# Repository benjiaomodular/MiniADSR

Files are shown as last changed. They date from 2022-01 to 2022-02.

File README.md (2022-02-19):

# MiniADSR

A four-parameter envelope generator based on Rene Schmitz' [The Fastest Envelope in the West](https://www.schmitzbits.de/adsr.html). More info on my website: https://benjiaomodular.com/post/2022-02-02-mini-adsr/

# Versions

## 1.0.1
Quick fixes for v1.0
- Fixed connection of R7 to Q2 pin 1
- Updated C2 value to 10uF
- Change sustain pot from 1M to 10k
- C3 from 100uF to 1uF
- Added version numbers
- Flipped power connectors 180deg to accomodate larger IDC connectors.

## 1.0
Initial design.

### Issues
- Wrong connection from R7
- Wrong value for C3 and Sustain pot

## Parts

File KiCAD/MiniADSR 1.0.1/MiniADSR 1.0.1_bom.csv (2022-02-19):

Reference | Quantity | Value | Footprint | Datasheet | Part # | Part Page
C1 | 1 | 10nF | Capacitor_THT:C_Rect_L7.2mm_W2.5mm_P5.00mm_FKS2_FKP2_MKS2_MKP2 | ~ | MMK5103K50J01L4BULK
C2 | 1 | 10uF | Capacitor_THT:CP_Radial_D5.0mm_P2.50mm | ~ | UVR1E100MDD1TD
C3 | 1 | 1uF* | Capacitor_THT:CP_Radial_D5.0mm_P2.50mm | ~ | ESC105M050AC3AA
C4 C5 | 2 | 100uF | Capacitor_THT:CP_Radial_D5.0mm_P2.50mm | ~ | ESH107M010AC3AA
C6 C7 | 2 | 100nF | Capacitor_THT:C_Rect_L7.2mm_W2.5mm_P5.00mm_FKS2_FKP2_MKS2_MKP2 | ~ | R82DC3100AA50K
D1 D2 D3 D4 D5 | 5 | 1N4148 | Diode_THT:D_DO-35_SOD27_P7.62mm_Horizontal | https://assets.nexperia.com/documents/data-sheet/1N4148_1N4448.pdf | 1N4148
D6 | 1 | PWR_LED | LED_THT:LED_D3.0mm | ~
D7 | 1 | OUTPUT_LED | LED_THT:LED_D3.0mm | ~
J1 | 1 | INPUT | benjiaomodular:AudioJack_3.5mm | ~
J2 | 1 | OUTPUT | benjiaomodular:AudioJack_3.5mm | ~
J3 | 1 | JST_BUS | Connector_JST:JST_XH_B6B-XH-A_1x06_P2.50mm_Vertical | ~
J4 | 1 | ControlBoard_Pins | Connector_PinSocket_2.54mm:PinSocket_1x14_P2.54mm_Vertical | ~
J5 | 1 | IDC_BUS | Connector_IDC:IDC-Header_2x05_P2.54mm_Vertical | ~
J6 | 1 | MainBoard_Pins | Connector_PinHeader_2.54mm:PinHeader_1x14_P2.54mm_Vertical | ~
POT_ATTACK1 POT_RELEASE1 POT_DECAY1 | 3 | 1M | benjiaomodular:Potentiometer_RV09 | ~ | RV09AF-40-20K-B1M
POT_SUSTAIN1 | 1 | 10K | benjiaomodular:Potentiometer_RV09 | ~ | RV09AF-40-20K-B10K
Q1 Q2 Q3 | 3 | BC547 | Package_TO_SOT_THT:TO-92_Inline_Wide | https://www.onsemi.com/pub/Collateral/BC550-D.pdf | BC547CTFR
R1 R5 R11 R12 | 4 | 10k | Resistor_THT:R_Axial_DIN0207_L6.3mm_D2.5mm_P7.62mm_Horizontal | ~ | MF1/4DC1002F
R2 R4 R6 R9 | 4 | 4.7k | Resistor_THT:R_Axial_DIN0207_L6.3mm_D2.5mm_P7.62mm_Horizontal | ~ | MFR-25FTE52-4K7
R3 | 1 | 22k | Resistor_THT:R_Axial_DIN0207_L6.3mm_D2.5mm_P7.62mm_Horizontal | ~ | MF1/4DCT52R2202F
R7 R8 R10 | 3 | 100R | Resistor_THT:R_Axial_DIN0207_L6.3mm_D2.5mm_P7.62mm_Horizontal | ~ | MFR-25FTE52-100R
U1 | 1 | LM555xN | Package_DIP:DIP-8_W7.62mm | http://www.ti.com/lit/ds/symlink/lm555.pdf | LM555CN/NOPB
U2 | 1 | TL072 | Package_DIP:DIP-8_W7.62mm | http://www.ti.com/lit/ds/symlink/tl071.pdf | TL072BCP

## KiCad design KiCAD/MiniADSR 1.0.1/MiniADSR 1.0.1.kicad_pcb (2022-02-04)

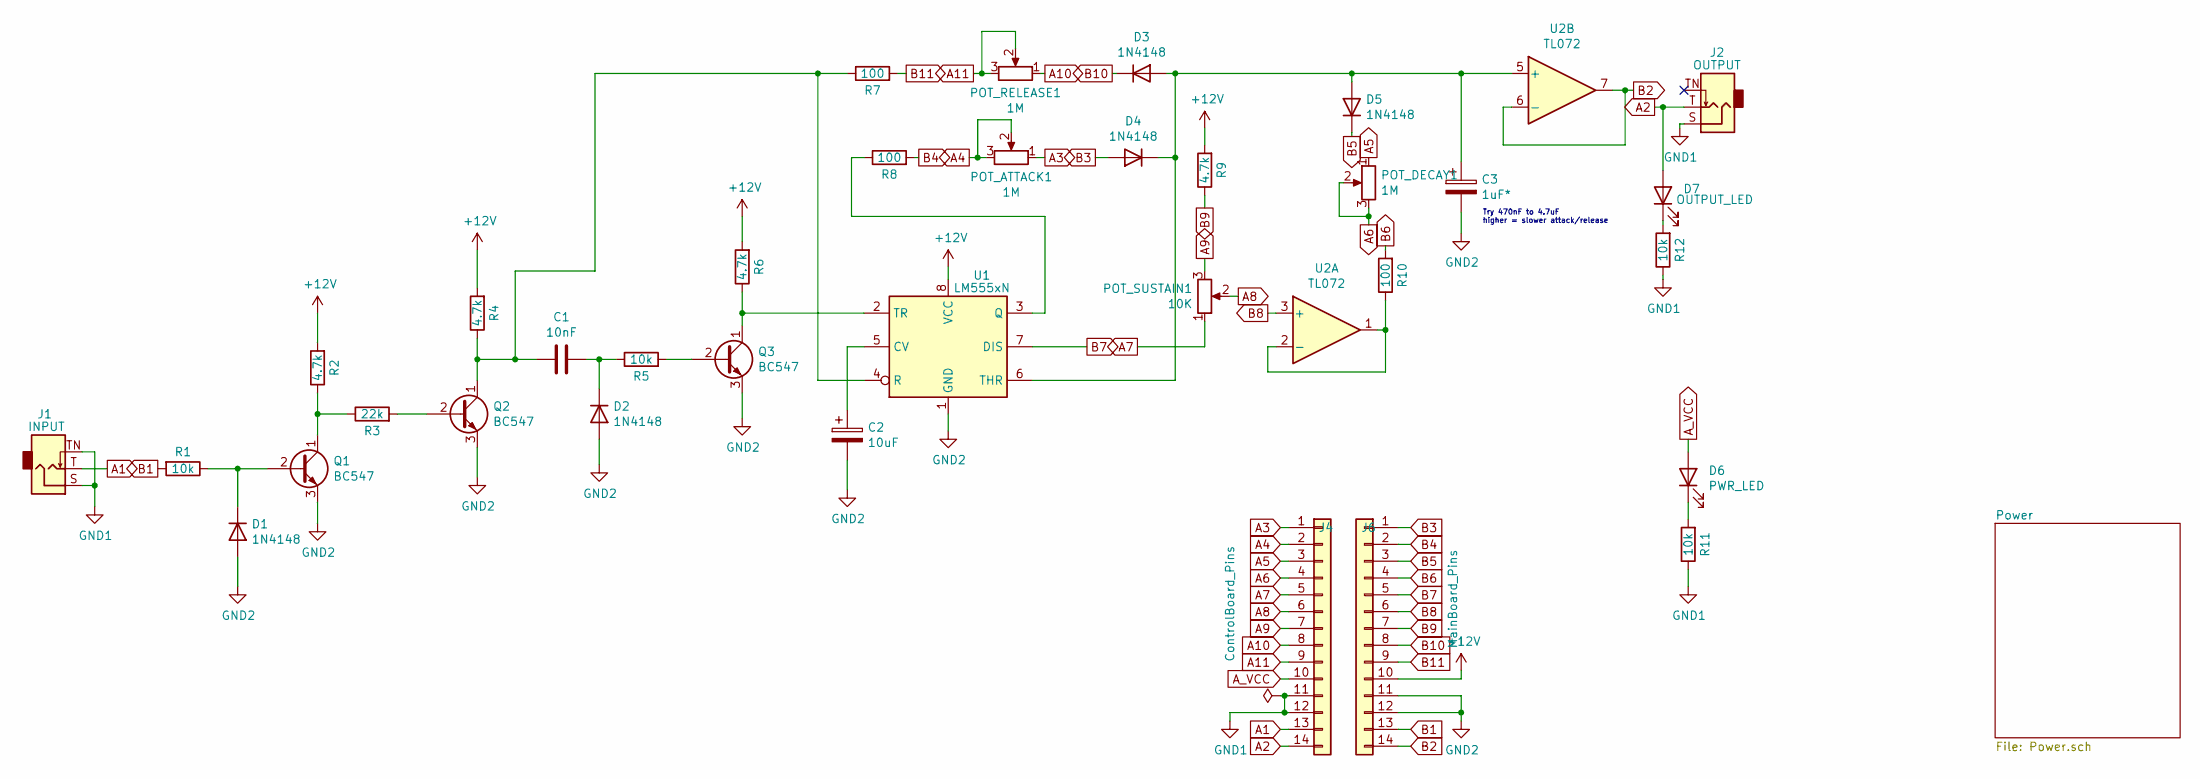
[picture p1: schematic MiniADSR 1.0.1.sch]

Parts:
C1: 10nF; C_Rect_L7.2mm_W2.5mm_P5.00mm_FKS2_FKP2_MKS2_MKP2
C2: 10uF; CP_Radial_D5.0mm_P2.50mm
C3: 1uF*; CP_Radial_D5.0mm_P2.50mm
D1, D2, D3, D4, D5: 1N4148; D_DO-35_SOD27_P7.62mm_Horizontal
D6: PWR_LED; LED_D3.0mm
D7: OUTPUT_LED; LED_D3.0mm
J1: INPUT; AudioJack_3.5mm
J2: OUTPUT; AudioJack_3.5mm
J4: ControlBoard_Pins; PinSocket_1x14_P2.54mm_Vertical
J6: MainBoard_Pins; PinHeader_1x14_P2.54mm_Vertical
POT_ATTACK1: 1M; Potentiometer_RV09
POT_DECAY1: 1M; Potentiometer_RV09
POT_RELEASE1: 1M; Potentiometer_RV09
POT_SUSTAIN1: 10K; Potentiometer_RV09
Q1, Q2, Q3: BC547; TO-92_Inline_Wide
R1, R5, R11, R12: 10k; R_Axial_DIN0207_L6.3mm_D2.5mm_P7.62mm_Horizontal
R2, R4, R6, R9: 4.7k; R_Axial_DIN0207_L6.3mm_D2.5mm_P7.62mm_Horizontal
R3: 22k; R_Axial_DIN0207_L6.3mm_D2.5mm_P7.62mm_Horizontal
R7, R8, R10: 100; R_Axial_DIN0207_L6.3mm_D2.5mm_P7.62mm_Horizontal
U1: LM555xN; DIP-8_W7.62mm
U2: TL072; DIP-8_W7.62mm

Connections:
A1: J1.T, J4.13
A2: D7.2 (A), J2.T, J4.14
A3: J4.1, POT_ATTACK1.1
A4: J4.2, POT_ATTACK1.2, POT_ATTACK1.3
A5: J4.3, POT_DECAY1.1
A6: J4.4, POT_DECAY1.2, POT_DECAY1.3
A7: J4.5, POT_SUSTAIN1.1
A8: J4.6, POT_SUSTAIN1.2
A9: J4.7, POT_SUSTAIN1.3
A10: J4.8, POT_RELEASE1.1
A11: J4.9, POT_RELEASE1.2, POT_RELEASE1.3
A_VCC: D6.2 (A), J4.10
B1: J6.13, R1.2
B2: J6.14, U2.6 (-), U2.7
B3: D4.2 (A), J6.1
B4: J6.2, R8.2
B5: D5.1 (K), J6.3
B6: J6.4, R10.2
B7: J6.5, U1.7 (DIS)
B8: J6.6, U2.3 (+)
B9: J6.7, R9.1
B10: D3.1 (K), J6.8
B11: J6.9, R7.2
GND1: J1.S, J1.TN, J2.S, J4.11, J4.12, R11.1, R12.1
unnamed: C1.1, D2.1 (K), R5.1
unnamed: C1.2, Q2.1 (C), R4.1, R7.1, U1.4 (R)
unnamed: C2.1, U1.5 (CV)
unnamed: C3.1, D3.2 (A), D4.1 (K), D5.2 (A), U1.6 (THR), U2.5 (+)
unnamed: D1.1 (K), Q1.2 (B), R1.1
unnamed: D6.1 (K), R11.2
unnamed: D7.1 (K), R12.2
unnamed: Q1.1 (C), R2.1, R3.1
unnamed: Q2.2 (B), R3.2
unnamed: Q3.1 (C), R6.1, U1.2 (TR)
unnamed: Q3.2 (B), R5.2
unnamed: R8.1, U1.3 (Q)
unnamed: R10.1, U2.1, U2.2 (-)

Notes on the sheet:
Try 470nF to 4.7uF higher = slower attack/release

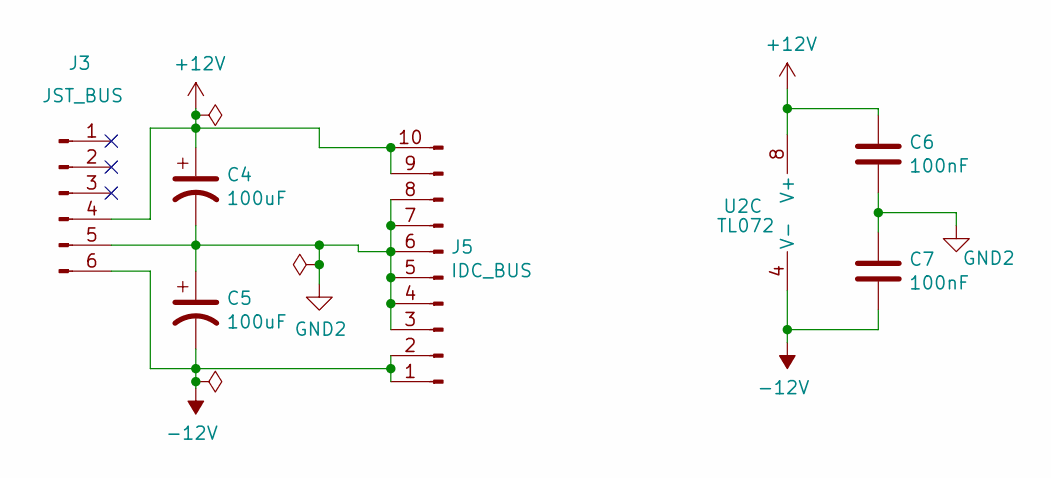
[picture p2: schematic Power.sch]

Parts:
C4, C5: 100uF; CP_Radial_D5.0mm_P2.50mm
C6, C7: 100nF; C_Rect_L7.2mm_W2.5mm_P5.00mm_FKS2_FKP2_MKS2_MKP2
J5: IDC_BUS; IDC-Header_2x05_P2.54mm_Vertical
J7: JST_BUS; JST_XH_B6B-XH-A_1x06_P2.50mm_Vertical
U2: TL072; DIP-8_W7.62mm

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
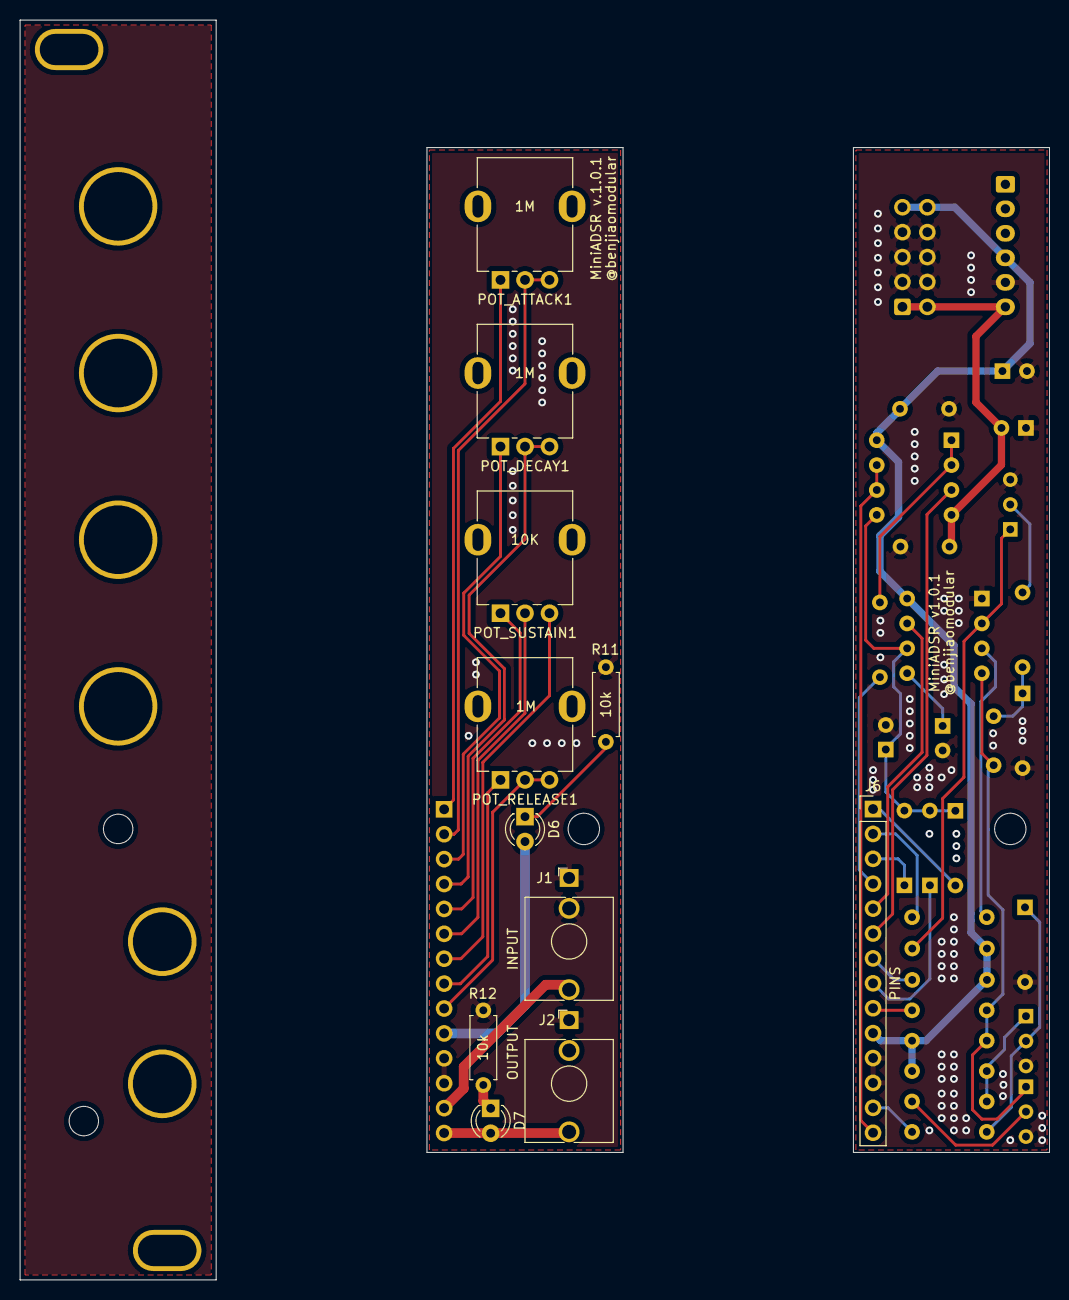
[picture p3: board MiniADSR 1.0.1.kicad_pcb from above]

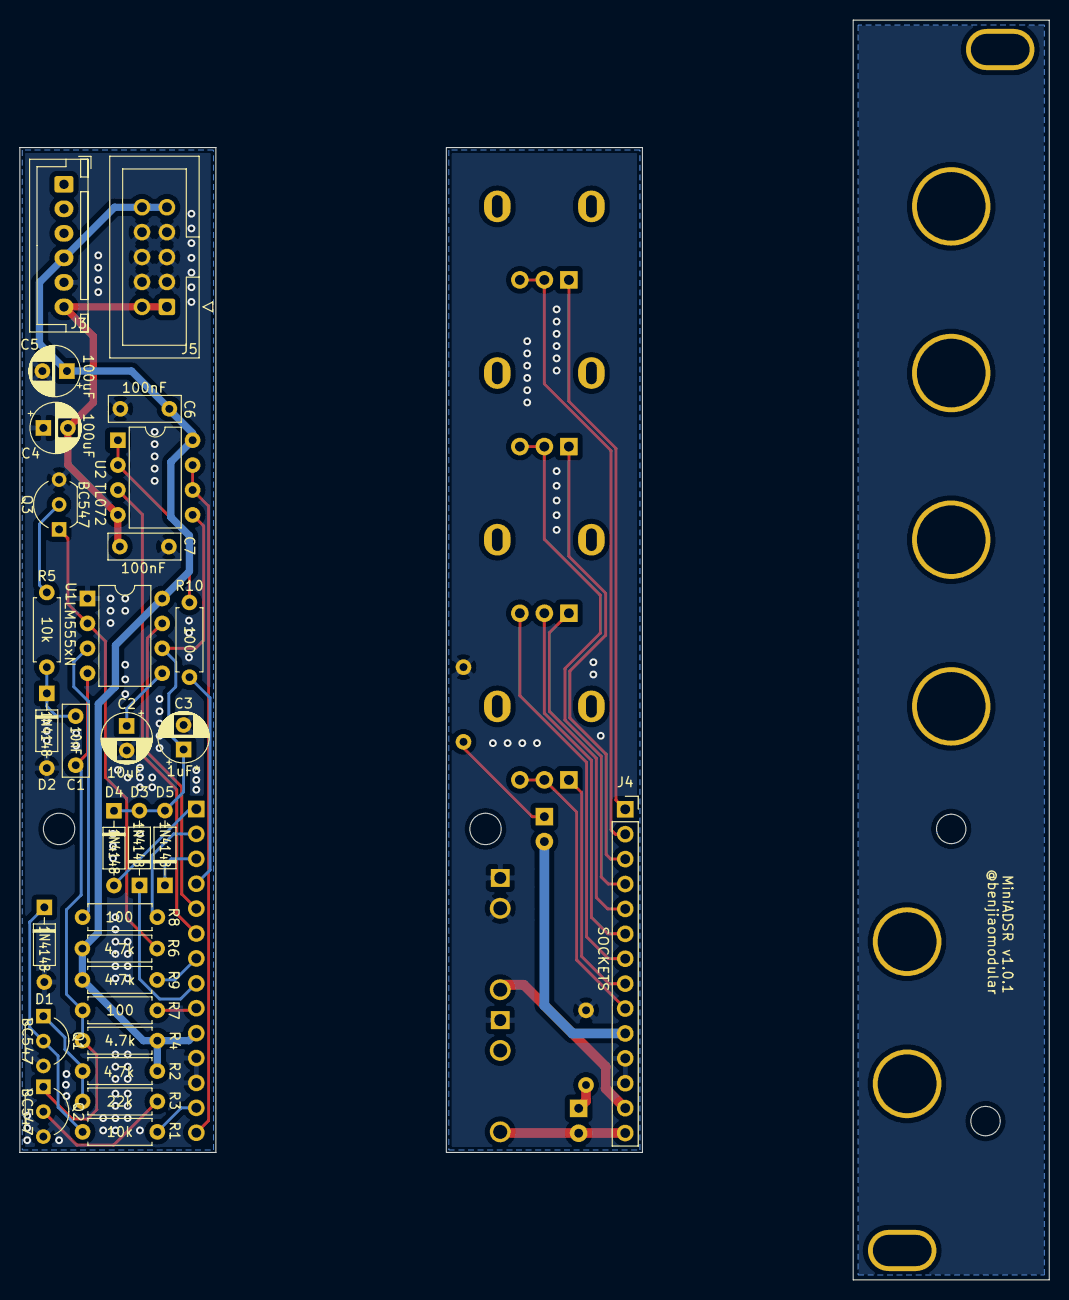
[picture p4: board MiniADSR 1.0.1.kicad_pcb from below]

Board: 2 copper layers, 105.0 x 128.5 mm, 41 parts (30 on the bottom side), 40 nets.

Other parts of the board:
J3: JST_BUS; JST_XH_B6B-XH-A_1x06_P2.50mm_Vertical

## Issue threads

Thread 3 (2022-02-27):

Incorrect panel mounting hole location

duckythescientist, 2022-02-27:
According to the Doepfer specs, the mounting hole on the left side of the panel should be 7.5mm from the edge (1.5HP minus the kerf/clearance of the panel width). Design version 1.0.1 has the hole at 5.08mm. The hole on the right is also misaligned by 0.5HP.

This means the module either fits excessively snugly against the module on one side of it or it has to be mounted with a 0.5HP gap on both sides.

benjiao, 2022-02-27:
Oh no. Thanks for pointing this out, @duckythescientist. I did add the 7.5mm guide lines, but I must have nudged the holes somewhere in the process. I'll correct it in the next subversion.

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

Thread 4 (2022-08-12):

Keep boards under 100mm

benjiao, 2022-08-12:
For the main board and control board, adjust height to at most 100mm to reduce printing cost

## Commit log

2022-01-07 Updated front panel labels
    [MiniADSR 1.0.kicad_pcb]
2022-01-09 Added fabrication files
    [MiniADSR 1.0 - Control Panel-B_Cu.gbr, MiniADSR 1.0 - Control Panel-B_Mask.gbr, MiniADSR 1.0 - Control Panel-B_Paste.gbr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]
2022-01-17 Started 1.1, refined labels
    [MiniADSR 1.1.kicad_pcb, MiniADSR 1.1.sch, Power.sch]
2022-01-17 Adjusted graphic line thickness
    [MiniADSR 1.1.kicad_pcb]
2022-01-17 Tweaked front panel print
    [MiniADSR 1.1.kicad_pcb]
2022-01-19 Added labels to pot footprints
    [MiniADSR 1.1.kicad_pcb]
2022-01-19 nudged IC labels
    [MiniADSR 1.1.kicad_pcb]
2022-01-19 Added fixes after fist build
    [MiniADSR 1.1.kicad_pcb]
2022-01-19 Added version number
    [MiniADSR 1.1.kicad_pcb]
2022-01-20 increased c3 as recommended by in original design
    [MiniADSR 1.0.kicad_pcb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]
2022-01-20 Redesigned PCB layout, added cap for longer decay
    [MiniADSR 1.1.kicad_pcb, MiniADSR 1.1.sch, Power.sch]
2022-02-01 Added v1.0.1 for minor corrections on first version
    [MiniADSR 1.0.1 - Control-B_CrtYd.gbr, MiniADSR 1.0.1 - Control-B_Cu.gbr, MiniADSR 1.0.1 - Control-B_Fab.gbr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]
2022-02-04 Flipped power connectors for v1.0.1
    [MiniADSR 1.0.1 - Control-B_CrtYd.gbr, MiniADSR 1.0.1 - Control-B_Cu.gbr, MiniADSR 1.0.1 - Control-B_Fab.gbr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]
2022-02-19 Updated readme for 1.0.1
    [MiniADSR 1.0.1_bom.csv]
